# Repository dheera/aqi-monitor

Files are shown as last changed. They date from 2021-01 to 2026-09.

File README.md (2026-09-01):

# aqi-monitor

This DIY air quality monitor will measure:

- temperature
- humidity
- pressure
- gas
- CO2
- number of particles
- ozone (expansion)
- earthquakes through an IMU (expansion)
- radioactivity (expansion)

There's an optional case and screen for both. The code is set up to allow you to only use a subset of sensors.

By default, results are streamed periodically to a self-hosted server (see [server/](server/)) running InfluxDB and Grafana on your LAN, for easy inspection and alerting.

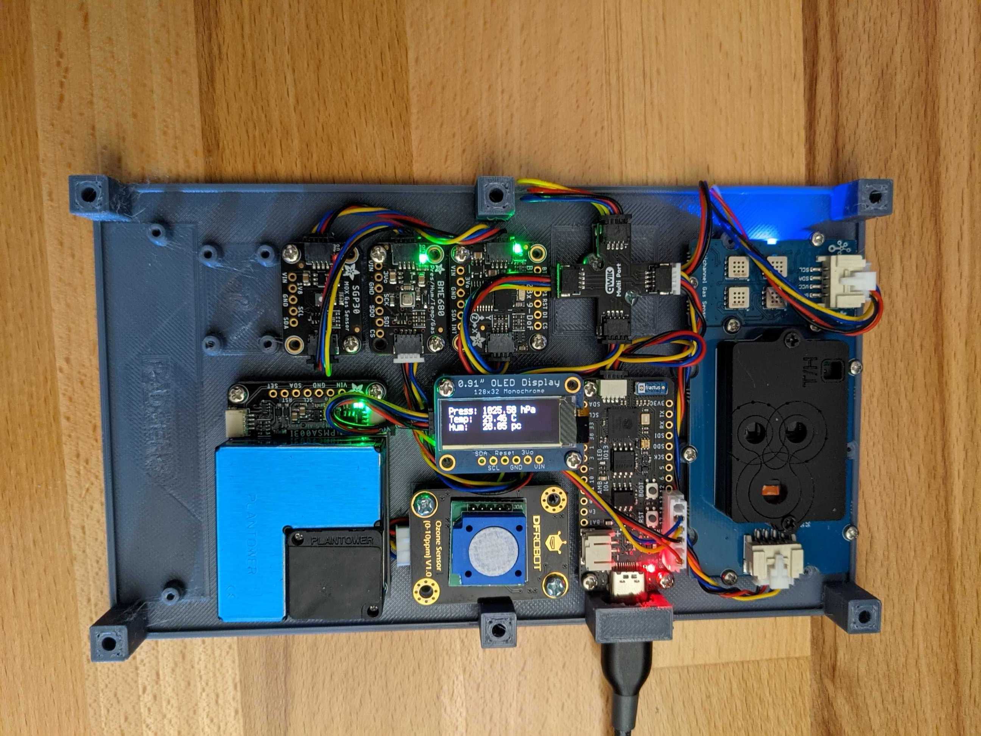
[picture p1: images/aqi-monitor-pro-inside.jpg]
sensor
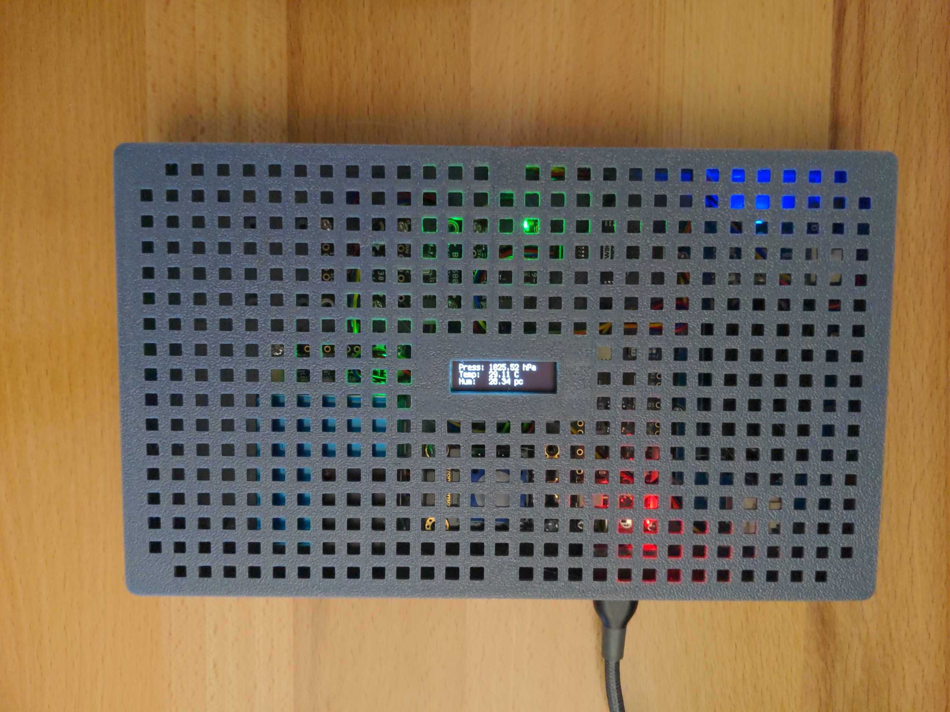
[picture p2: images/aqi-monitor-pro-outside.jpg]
cover
|  |  |
| --- | --- |

## BOM

If you want to encase the electronics, an STL file for 3D printing a case is in the [design folder](design/).
Make sure you get the right case for either base or base+expansion set.

### Base set

| item | function | ~price | notes |
| --- | --- | --- | --- |
| [Adafruit FeatherS2 - ESP32-S2](https://www.adafruit.com/product/4769) | microcontroller | $22 | adafruit boards are often available on digikey and amazon if adafruit is sold out |
| [Adafruit BME680](https://www.adafruit.com/product/3660) | Temp/Humidity/Pressure/Gas | $19 | incredibly sensitive pressure sensor, can possibly detect which floor of a building robot is on |
| [Adafruit PMSA003I](https://www.adafruit.com/product/4632) | PM1, PM2.5, PM10 particle sensor | $45 | this messes up the I2C bus it is placed on, thankfully ESP32-S2 has 2 I2C buses so this can have its own bus |
| [SeeedStudio SCD30](https://www.seeedstudio.com/Grove-CO2-Temperature-Humidity-Sensor-SCD30-p-2911.html) | CO2/temp/humidity sensor | $60 | NDIR CO2 sensor (much better than chemical); buy from Mouser for faster shipping to US destinations |

For a total of ~$146 excluding screen and case.

The STL files for 3D printing the base case can be found in the design folder.

### Expansion set

These are extra sensors you can purchase in addition to the base set.

| item | function | ~price | notes |
| --- | --- | --- | --- |
| [Adafruit BNO085](https://github.com/adafruit/Adafruit_BNO08x) | IMU (Earthquake detection) | $20 | this is a really good IMU |
| [SeeedStudio Multichannel Gas Sensor v2](https://www.seeedstudio.com/Grove-Multichannel-Gas-Sensor-v2-p-4569.html) | CO, VOC, alcohol, NO2 | $35 | buy from Mouser for faster shipping to US destinations |
| [DFRobot I2C Ozone Sensor](https://www.dfrobot.com/product-2005.html) | ozone | $49 | buy from Mouser for faster shipping to US destinations |
| [Geiger Counter](https://www.ebay.com/itm/Arduino-dosimeter-module-Geiger-Counter-RadSens-Radiation-Detector-board-pcb/184495660379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) | Radioactivity | $45 | ships from Russia; not yet tested; couldn't find a US-stocked I2C Geiger counter |

### Optional Screen

| item | function | ~price | notes |
| --- | --- | --- | --- |
| [Monochrome 0.91" 128x32 I2C OLED Display](https://www.adafruit.com/product/4440) | screen | $12.5  | optional |

## Instructions

### Wire the electronics

See pictures

### Set up the server

1. Follow [server/README.md](server/README.md) to bring up the InfluxDB + Grafana stack in Docker on a machine on your LAN, and generate an API key.

### Modify the parameters

1. Download the [code](code/) and open `wifi.json`. Enter your Wifi name (SSID) and password. The microcontroller needs WiFi access to be able to upload the sensor data.
2. Open `credentials.json` and set `url` to your server's address (e.g. `http://192.168.1.50:8080`), `device_id` to a name for this monitor, and `api_key` to the key you generated for the server.
3. Open [config.py](code/config.py) and modify any of the parameters (`LOAD_XXX`) to match your configuration.

### Load on the code

Plug the microcontroller into your computer using a USB-C cable. It should appear in your file explorer. Copy and replace the files from the `code` folder including the files you modified into the `CIRCUITPY` folder.

Press reset. You should see data coming through on the Grafana dashboard.

### Calibrate the sensors

The BME680 and SCD30 tend to read several degrees high for temperature due to
self-heating from nearby components. Correct for this once per physical unit:

1. Let the device run outside (or wherever you have a reliable reference
   temperature) for a few minutes so the sensors reach steady state.
2. Read `bme680.temperature` and `scd30.temperature` over the serial REPL (see
   Troubleshooting below) and compare against your reference thermometer.
3. In `config.py`, set `BME680_TEMP_OFFSET` and `SCD30_TEMP_OFFSET` to
   `sensor_reading - reference_temperature` for each sensor, then reload. Both
   default to `0.0` (no correction) until calibrated.

The SCD30's CO2 reading can drift over time and benefits from a one-time
forced recalibration (FRC) against a known-good reference, typically fresh
outdoor air (check the current atmospheric CO2 level rather than assuming the
outdated "400 ppm" figure). The sensor must have been running continuously
for at least 2 minutes before this. Over the serial REPL:

```
import board, busio, adafruit_scd30
i2c = busio.I2C(board.SCL, board.SDA, frequency=400000)
scd = adafruit_scd30.SCD30(i2c)
scd.forced_recalibration_reference = 425  # replace with your reference ppm
```

Unlike the temperature offsets, this value is stored on the SCD30's own
non-volatile memory rather than in this repo - it isn't reapplied
automatically and won't carry over if you swap sensors. There's no way to
read back when a sensor was last calibrated, so note the date and reference
value you used somewhere (e.g. a commit message) when you do it.

An alternative to a one-time FRC is enabling Automatic Self-Calibration
(`scd.self_calibration_enabled = True`), which continuously self-corrects
over about a week assuming the sensor sees fresh air periodically. Its
enabled state is not stored in non-volatile memory, so it turns off after
every reboot unless re-enabled in `code.py`.

## Troubleshooting

From a terminal window, you can log into the Feather S2 microcontroller to read the logs using

```
sudo screen /dev/ttyACM0 115200
```

The actual device name might be different. This opens up a python terminal. You can re-run the code by typing `import code`.

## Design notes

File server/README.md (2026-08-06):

# aqi-monitor server

Self-hosted replacement for the (now defunct) Freedom Robotics upload target. Runs three
containers on your LAN:

- **influxdb** — time-series database that stores the sensor readings
- **receiver** — small HTTP API the microcontroller posts JSON to; writes into InfluxDB
- **grafana** — dashboards and alerting on top of InfluxDB, pre-provisioned with a
  datasource and a starter dashboard (`grafana/provisioning/dashboards/aqi-monitor.json`)

## Setup

1. Copy the env template and fill in real secrets:

   ```
   cp .env.example .env
   ```

   Generate `INFLUXDB_TOKEN` and `API_KEY` as long random strings (e.g. `openssl rand -hex 32`).

2. Add a config file for each device under `devices/<device_id>.json` (an example is
   already there for `aqi-monitor-01`). This is where SGP30 IAQ baselines and any
   per-topic calibration coefficients live; the microcontroller fetches this at boot via
   `GET /devices/<device_id>/config`.

3. Start the stack:

   ```
   docker compose up -d --build
   ```

4. Grafana is at `http://<host>:3000` (login `admin` / `GRAFANA_PASSWORD` from `.env`).
   InfluxDB's own UI is at `http://<host>:8086` if you want to query data directly.

5. On the microcontroller, point `code/credentials.json` at this server:

   ```json
   {
     "url": "http://<host>:8080",
     "device_id": "aqi-monitor-01",
     "api_key": "<same value as API_KEY in .env>"
   }
   ```

## Data model

The receiver flattens each incoming message's nested `data` dict into InfluxDB fields
(e.g. `{"pm25_standard": 12}` under topic `pmsa003i/pm25_standard` becomes measurement
`pmsa003i_pm25_standard`, field `data`). Every point is tagged with `device=<device_id>`,
so a single stack can ingest multiple monitors.

## Long-term archival (optional)

InfluxDB retention can be capped and older data exported/archived to S3 on a schedule
(e.g. `influx backup` + a cron job pushing to a bucket) if you want cheap cold storage
beyond what you keep live in Grafana. This isn't set up by default.

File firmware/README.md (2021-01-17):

Modified CircuitPython firmware for FeatherS2 that resolves this bug
https://github.com/adafruit/circuitpython/issues/3988

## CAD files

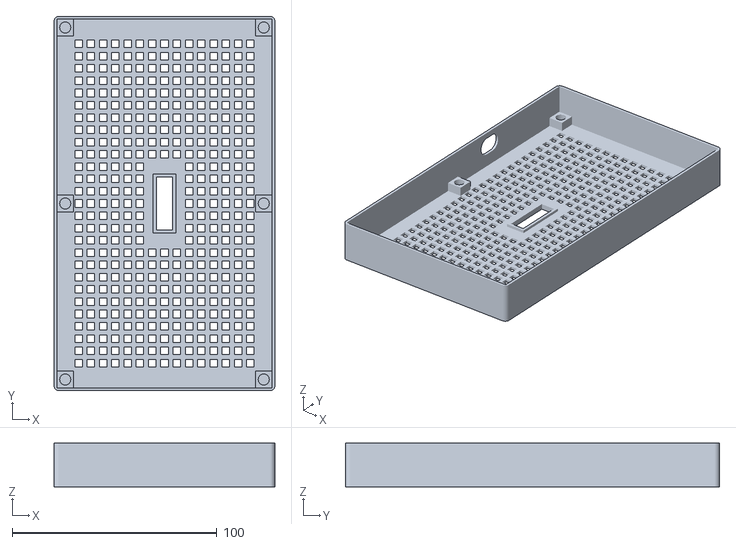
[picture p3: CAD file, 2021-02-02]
design/aqi-monitor-pro-cover.stl
108.0 x 183.0 x 21.5

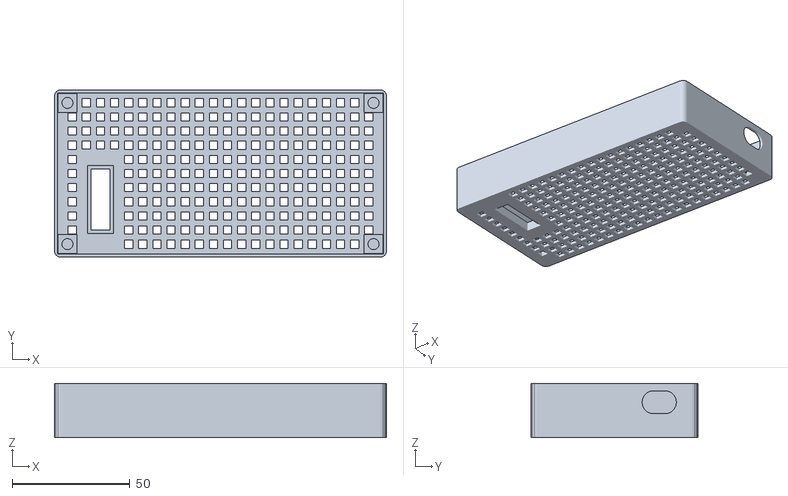
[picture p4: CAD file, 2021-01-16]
design/aqi-monitor-basic-cover.stl
141.0 x 71.0 x 23.0

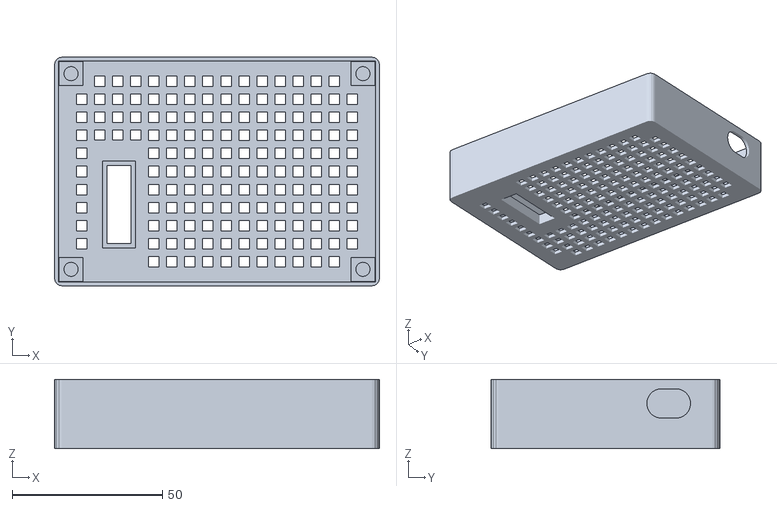
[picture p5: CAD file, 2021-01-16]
design/aqi-monitor-nano-cover.stl
108.0 x 76.0 x 23.0

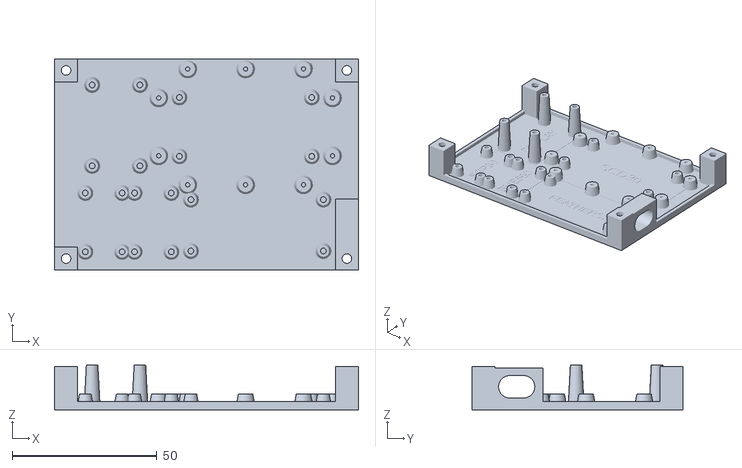
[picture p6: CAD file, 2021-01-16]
design/aqi-monitor-nano.stl
105.0 x 73.0 x 15.5

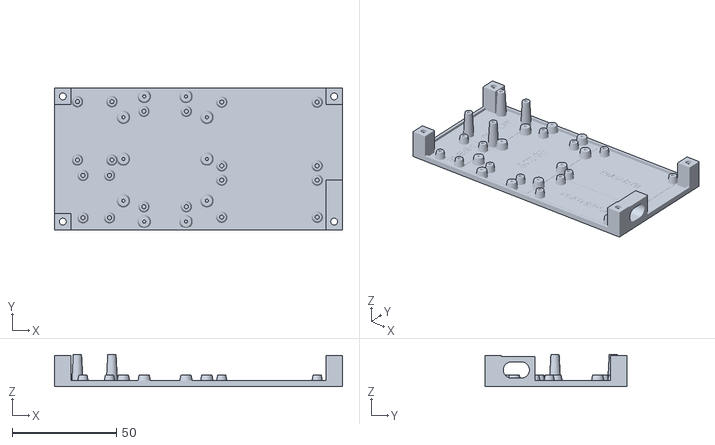
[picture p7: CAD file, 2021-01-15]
design/aqi-monitor-basic-base.stl
138.0 x 68.0 x 15.5

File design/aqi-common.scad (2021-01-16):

module usbplugshape(Q=12,R=7) {
    translate([-Q/2+R/2,0,0])
    cylinder(d=R,h=20,$fn=64);
    translate([Q/2-R/2,0,0])
    cylinder(d=R,h=20,$fn=64);
    cube_center([Q-R,R,20]);
}
    

module cube_center(dims,r=0,$fn=16) {
    if(r==0) {
        translate([-dims[0]/2, -dims[1]/2, 0])
        cube(dims);
    } else {
        minkowski() {
            translate([-(dims[0]-2*r)/2, -(dims[1]-2*r)/2, 0])
            cube([dims[0]-2*r,dims[1]-2*r,dims[2]]);
            cylinder(r=r,$fn=$fn,h=0.0001);
        }
    }
}




module usbport() {
    difference() {
    cube_center([8,18,13]);
    translate([-6,0,1+1.5+4])
    rotate([0,0,90])
    rotate([90,0,0])
        usbplugshape(Q=12.5,R=7.75);
    }
}

module usbplugshape(Q=12,R=7) {
    translate([-Q/2+R/2,0,0])
    cylinder(d=R,h=20,$fn=64);
    translate([Q/2-R/2,0,0])
    cylinder(d=R,h=20,$fn=64);
    cube_center([Q-R,R,20]);
}

module scd30() {
        difference() {
            union() {
    for(q=[-20:20:20]) for(r=[-20,20])
    translate([q,r,0]) standoff(sh=4,d=6,screw=2);
    for(q=[-30,30]) for(r=[-10,10])
    translate([q,r,0]) standoff(sh=4,d=6,screw=2);
    
    quadboard(W=2.0*25.4,H=1.0*25.4,w=1.8*25.4,h=.8*25.4,screw=2.5);
        cube_center([60,40,0.15]);
}
        linear_extrude(height = 0.5) text("SCD30", valign="center", halign="center",size=5);
    }
}


module tc6713() {
    difference() {
        cube_center([15+3,31+3,9.5]);
        translate([0,0,2.5])
        cube_center([15.3,31.3,8]);
        cube_center([13.3,31.3,8]);
        translate([0,11.15,0])
        cube_center([50,9,10]);
        translate([0,-11.15,0])
        cube_center([50,9,10]);
        cube_center([8,100,10]);
        translate([0,28,5])
        cube_center([30,30,10]);
        translate([0,-28,5])
        cube_center([30,30,10]);
    }
    translate([-20/2,0,0])
    standoff(sh=9.5);
    translate([20/2,0,0])
    standoff(sh=9.5);
}

module gamma() {
    
    
    difference() {
        cube_center([88,21,0.15]);
        linear_extrude(height = 0.5) text("RADSENS", valign="center", halign="center",size=4);
    }
    
    translate([83/2,21/2-8,0])
    standoff(sh=4,screw=2.5);
    translate([-83/2,21/2-8,0])
    standoff(sh=4,screw=2.5);
}

module mcgasv2() {
    translate([20/2,-40/2+10,0]) standoff(sh=4,d=6,screw=2);
    translate([-20/2,-40/2+10,0]) standoff(sh=4,d=6,screw=2);
    translate([20/2,40/2-10,0]) standoff(sh=4,d=6,screw=2);
    translate([-20/2,40/2-10,0]) standoff(sh=4,d=6,screw=2);
    translate([0,40/2,0]) standoff(sh=4,d=6,screw=2);
    translate([0,-40/2,0]) standoff(sh=4,d=6,screw=2);
    difference() {
        cube_center([20,40,0.15]);
        rotate([0,0,90])
        linear_extrude(height = 0.5) text("MCGASV2", valign="center", halign="center",size=4);
    }
}



module display() {
    quadboard(W=1.35*25.4,w=1.10*25.4,H=0.86*25.4,h=0.65*25.4, text = "DISPLAY",screw=2.5,sh=14);
}

module feathers2() {
    quadboard(W=50.5,w=45.75,H=22.5,h=17.75, text = "FEATHERS2",screw=2.5);
}

module pmsa003i() {
    quadboard(W=2.00*25.4,w=1.8*25.4,H=1.4*25.4,h=1.2*25.4, text="PMSA003I", screw=2.5);
}

module sen0321() {
    quadboard(W=37,w=30,H=27,h=20,sh=6.5,screw=3,d=6, text="SEN0321");
}

module bme680() {
    quadboard(W=1.0*25.4,w=0.8*25.4,H=0.70*25.4,h=0.5*25.4, text="BME680", screw=2.5);
}

module tsl2591() {
    quadboard(W=1.0*25.4,w=0.8*25.4,H=0.70*25.4,h=0.5*25.4, screw=2.5, text="?");
}

module sgp30() {
    quadboard(W=1.0*25.4,w=0.8*25.4,H=0.70*25.4,h=0.5*25.4, text="SGP30", screw=2.5);
}

module bno085() {
    quadboard(W=1.0*25.4,w=0.8*25.4,H=0.90*25.4,h=0.7*25.4, text="BNO085", screw=2.5);
}

module qwiicstar() {
    translate([-7.5/2,-7.5/2,0]) standoff(sh=4,d=6,screw=3);
    translate([7.5/2,7.5/2,0]) standoff(sh=4,d=6,screw=3);
    cube_center([26,26,0.15]);
}

module quadboard(W=25,w=20.25,H=18,h=13,sh=4,screw=2.5,d=5, text = "") {
    translate([-w/2,-h/2,0]) standoff(sh=sh,screw=screw,d=d);
    translate([-w/2,h/2,0]) standoff(sh=sh,screw=screw,d=d);
    translate([w/2,-h/2,0]) standoff(sh=sh,screw=screw,d=d);
    translate([w/2,h/2,0]) standoff(sh=sh,screw=screw,d=d);
    difference() {
        cube_center([W,H,0.15]);
        linear_extrude(height = 0.5) text(text, valign="center", halign="center",size=4);
    }
}

module standoff(d=5,screw=1.5,sh=4) {
    difference() {
        cylinder(d1=d+0.5,d2=d-1,h=sh,$fn=32);
        cylinder(d=screw-0.5,h=sh+1,$fn=32);
    }
}

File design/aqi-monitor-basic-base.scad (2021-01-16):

include<aqi-common.scad>;

/*
// fit testing
translate([0,0,23])
rotate([0,180,180])
import("aqi-monitor-basic-cover.stl");
*/

// width and height of board
W=138;
H=68;

// how much the whole board layout is offset from origin
TX=34;
TY=-23;

// how much the display is offset from center
DX=-51;
DY=11;

difference() {
    union() {
            cube_center([W,H,1.5]);
        difference() {
            cube_center([W,H,3]);
            cube_center([W-3,H-3, 6]);
            
        }
        for(s=[-1,1]) for(t=[-1,1])
            translate([s*(W-8)/2,t*(H-8)/2])
            cube_center([8,8,15]);
    }
    for(s=[-1,1]) for(t=[-1,1]) {
        translate([s*(W-8)/2,t*(H-8)/2]) {
            cylinder(d=6,h=3.5,$fn=32);
            cylinder(d=3.3,h=50,$fn=32);
        }
    }
}

translate([TX,TY,1.5]) {
    translate([31,4,0]) usbport();
    
    translate([0,4,0])
    feathers2();
    
    translate([-83,5,0])
    rotate([0,0,90])
    bme680();
    
    translate([0,35,0])
    pmsa003i();
    
    translate([-50,23,0])
    rotate([0,0,90])
    scd30();
    
    translate([DX,DY,0])
    translate([-TX,-TY,0])
    translate([(9-6.5)/2,(7.5-2.5)/2,0])
    rotate([0,0,90])
    display();
}

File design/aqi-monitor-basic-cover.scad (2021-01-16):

include<aqi-common.scad>;

W=138;
H=68;
TX=34;
TY=-23;
DX=-51;
DY=11;

{
  difference() {
      union() {
    cube_center([W+3,H+3,23],r=2.5);
          
      }
  translate([0,0,1.5])
  difference() {
      cube_center([W+.3,H+.3,23]);
      
      translate([DX,-DY,0])
      cube_center([11,29,0.5+2.5]);
  }
  difference() {
      for(x=[-63:6:63]) for(y=[-30:6:30])
      translate([x,y,0])
      cube_center([3.5,3.5,3]);
      
      translate([DX,-DY,0])
      cube_center([17,43,100]);
  }
  
  //translate([-60,27+4,23-8])
  translate([31+TX,-(   4+TY),23-8]) 
  //cube_center([100,16,11]);
  rotate([90,0,90]) {
        usbplugshape(Q=12.5+2,R=7.75+2);
    }
  
  translate([DX,-DY,0])
  cube_center([8,26,100]);
         
}

difference() {
              for(s=[-1,1]) for(t=[-1,1])
            translate([s*(W-8)/2,t*(H-8)/2])
            cube_center([8,8,8-0.15]);
          
  for(s=[-1,1]) for(t=[-1,1]) {
        translate([s*(W-8)/2,t*(H-8)/2,3]) {
            cylinder(d=4.7,h=5,$fn=32);
        }
    }
}

}

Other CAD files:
design/aqi-monitor-nano-cover.scad
design/aqi-monitor-nano.scad
design/aqi-monitor-pro-base.scad
design/aqi-monitor-pro-cover.scad

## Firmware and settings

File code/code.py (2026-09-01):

print("Starting ...")

import board
import busio
import display
import gc
import os
import sys
import time
import microcontroller
from config import *

time.sleep(5)

if LOAD_WATCHDOG:
    from watchdog import WatchDogMode
    w = microcontroller.watchdog
    w.timeout = 60.0
    w.mode = WatchDogMode.RESET
    w.feed()
    microcontroller.on_next_reset(microcontroller.RunMode.NORMAL)

print("import libraries")

if LOAD_UPLOAD:
    import nanolink
if LOAD_BME680:
    import adafruit_bme680
if LOAD_SGP30:
    import adafruit_sgp30
if LOAD_SCD30:
    import adafruit_scd30
if LOAD_MCGASV2:
    import seeed_mcgasv2
if LOAD_SEN0321:
    import dfrobot_ozone
if LOAD_BNO08X:
    import adafruit_bno08x
    from adafruit_bno08x.i2c import BNO08X_I2C
if LOAD_PMSA003I:
    from adafruit_pm25.i2c import PM25_I2C
if LOAD_RADSENSE:
    import radsense
if LOAD_WATCHDOG:
    w.feed()

print("init i2c")
gc.collect() # Clear memory before heavy sensor init
# Set to 400kHz for stability.
i2c = busio.I2C(board.SCL, board.SDA, frequency=400000)

if LOAD_PMSA003I:
    # PMSA003I needs its own i2c bus because it seems to mess with other i2c devices
    # it also needs a much lower i2c clock frequency per adafruit docs
    # fortunately the feathers2 has 2 i2c controllers and we can instantiate the 2nd one
    # on pins IO17 and IO18 which are very close to 3V and GND pins so
    # you can solder a JST-EH connector with 5 or more positions to [3V, 0, GND, 17, 18]
    # also, @unexpectedmaker warned on discord not to use IO0 for i2c
    i2c1 = busio.I2C(board.IO17, board.IO18, frequency=100000)

if LOAD_WATCHDOG:
    w.feed()

# Some sensor drivers (e.g. adafruit_bme680) block forever polling status
# registers instead of raising when the chip isn't actually on the bus, which
# would otherwise hang the watchdog-reset loop indefinitely. Scanning first
# and skipping absent addresses avoids ever calling into those drivers blind.
print("scanning i2c bus")
while not i2c.try_lock():
    pass
i2c_addrs = i2c.scan()
i2c.unlock()
print("i2c devices found:", [hex(a) for a in i2c_addrs])

if LOAD_PMSA003I:
    while not i2c1.try_lock():
        pass
    i2c1_addrs = i2c1.scan()
    i2c1.unlock()
    print("i2c1 devices found:", [hex(a) for a in i2c1_addrs])

if LOAD_BME680 and 0x77 not in i2c_addrs:
    print("bme680 not found on i2c bus scan")
    LOAD_BME680 = False
if LOAD_SGP30 and 0x58 not in i2c_addrs:
    print("sgp30 not found on i2c bus scan")
    LOAD_SGP30 = False
if LOAD_SCD30 and 0x61 not in i2c_addrs:
    print("scd30 not found on i2c bus scan")
    LOAD_SCD30 = False
if LOAD_MCGASV2 and 0x08 not in i2c_addrs:
    print("mcgasv2 not found on i2c bus scan")
    LOAD_MCGASV2 = False
if LOAD_SEN0321 and 0x73 not in i2c_addrs:
    print("sen0321 not found on i2c bus scan")
    LOAD_SEN0321 = False
if LOAD_BNO08X and 0x4A not in i2c_addrs:
    print("bno08x not found on i2c bus scan")
    LOAD_BNO08X = False
if LOAD_RADSENSE and 0x66 not in i2c_addrs:
    print("radsense not found on i2c bus scan")
    LOAD_RADSENSE = False

if LOAD_WATCHDOG:
    w.feed()

#If the display is physically disconnected or 
#has a loose wire, display.init(i2c) might crash 
#the entire script before it even starts monitoring
if LOAD_DISPLAY:
    print("init display")
    try:
        display.init(i2c)
    except Exception as e:
        print("Display not found or failed to init:", e)
        LOAD_DISPLAY = False # Disable display logic for the rest of the run


    if LOAD_WATCHDOG:
        w.feed()

print("init net")
display.show(0, "init net")

from net import requests, geo

if LOAD_WATCHDOG:
    w.feed()

if LOAD_UPLOAD:
    print("init link")
    display.show(0, "init link")
    link = nanolink.NanoLink(requests = requests, auto_sync = False)

    print("device config:")
    print(link.config)

    if LOAD_WATCHDOG:
        w.feed()

def log(text):
    print(text)
    link.log("info", text)
    link.sync()


if LOAD_BNO08X:
    print("init bno08x")
    display.show(0, "init bno08x")
    link.log("info", "init bno08x")
    link.sync()

    try:
        bno = BNO08X_I2C(i2c)
        bno.enable_feature(adafruit_bno08x.BNO_REPORT_ACCELEROMETER)
        bno.enable_feature(adafruit_bno08x.BNO_REPORT_GYROSCOPE)
        bno.enable_feature(adafruit_bno08x.BNO_REPORT_MAGNETOMETER)
        bno.enable_feature(adafruit_bno08x.BNO_REPORT_ROTATION_VECTOR)
    except Exception as e:
        print("bno08x not found or failed to init:", e)
        LOAD_BNO08X = False

    if LOAD_WATCHDOG:
        w.feed()

if LOAD_MCGASV2:
    print("init mcgasv2")
    display.show(0, "init mcgasv2")
    link.log("info", "init mcgasv2")
    link.sync()

    try:
        gas = seeed_mcgasv2.Gas(i2c)
    except Exception as e:
        print("mcgasv2 not found or failed to init:", e)
        LOAD_MCGASV2 = False

    if LOAD_WATCHDOG:
        w.feed()

if LOAD_BME680:
    print("init bme680")
    display.show(0, "init bme680")
    link.log("info", "init mcgasv2")
    link.sync()

    bme680 = None
    try:
        bme680 = adafruit_bme680.Adafruit_BME680_I2C(i2c)
    except Exception as e:
        print("bme680 not found or failed to init:", e)
        LOAD_BME680 = False

    if LOAD_WATCHDOG:
        w.feed()

if LOAD_SGP30:
    print("init sgp30")
    display.show(0, "init sgp30")
    link.log("info", "init sgp30")
    link.sync()

    try:
        sgp30 = adafruit_sgp30.Adafruit_SGP30(i2c)
        print("SGP30 serial # %04x-%04x-%04x" % tuple(sgp30.serial))
        sgp30.iaq_init()
        iaq_baseline = link.config.get("sgp30", {}).get("iaq_baseline", [0x8973, 0x8AAE])
        if len(iaq_baseline) != 2 or type(iaq_baseline[0]) != int or type(iaq_baseline[1]) != int:
            iaq_baseline = [0x8973, 0x8AAE]
        sgp30.set_iaq_baseline(iaq_baseline[0], iaq_baseline[1])
    except Exception as e:
        print("sgp30 not found or failed to init:", e)
        LOAD_SGP30 = False

    if LOAD_WATCHDOG:
        w.feed()

if LOAD_SCD30:
    print("init scd30")
    display.show(0, "init scd30")
    link.log("info", "init scd30")
    link.sync()

    try:
        scd30 = adafruit_scd30.SCD30(i2c)
        scd30.temperature_offset = SCD30_TEMP_OFFSET
    except Exception as e:
        print("scd30 not found or failed to init:", e)
        LOAD_SCD30 = False

    if LOAD_WATCHDOG:
        w.feed()

if LOAD_SEN0321:
    print("init sen0321")
    display.show(0, "init sen0321")
    link.log("info", "init sen0321")
    link.sync()

    try:
        ozone = dfrobot_ozone.DFRobot_Ozone(i2c)
        if ozone is not None:
            ozone.set_mode(dfrobot_ozone.MEASURE_MODE_AUTOMATIC)
    except Exception as e:
        print("sen0321 not found or failed to init:", e)
        LOAD_SEN0321 = False

    if LOAD_WATCHDOG:
        w.feed()

if LOAD_PMSA003I:
    print("init pm25")
    display.show(0, "init pm25")
    link.log("info", "init pm25")
    link.sync()

    pm25 = None
    try:
        pm25 = PM25_I2C(i2c1, None)
    except Exception as e:
        print("pmsa003i not found or failed to init:", e)
        LOAD_PMSA003I = False

    if LOAD_WATCHDOG:
        w.feed()

if LOAD_RADSENSE:
    print("init radsense")
    display.show(0, "init radsense")
    link.log("info", "init radsense")
    link.sync()

    try:
        radsense = radsense.Radsense_1_2(i2c)
    except Exception as e:
        print("radsense not found or failed to init:", e)
        LOAD_RADSENSE = False

display_page = 0

seq = 0

while True:

    display_page = (display_page + 1) % 6

    t = time.monotonic_ns()

    data = []

    if LOAD_PMSA003I:
        try:
            aqdata_filtered = {}
            aqdata = pm25.read()
            for key in aqdata:
               aqdata_filtered[key.replace(" ", "_")] = aqdata[key]
            data.append(("/pmsa003i/raw", "pmsa003i_msgs/RawData", aqdata_filtered))
            data.append(("/pmsa003i/pm10_standard", "std_msgs/Float32", {"data": aqdata_filtered["pm10_standard"]}))
            data.append(("/pmsa003i/pm25_standard", "std_msgs/Float32", {"data": aqdata_filtered["pm25_standard"]}))
            data.append(("/pmsa003i/pm100_standard", "std_msgs/Float32", {"data": aqdata_filtered["pm100_standard"]}))
            if display_page == 0:
                display.show(0, "PM2.5:  %.1f" % aqdata_filtered["pm25_standard"])
                display.show(1, "PM10:   %.1f" % aqdata_filtered["pm10_standard"])
                display.show(2, "PM100:  %.1f" % aqdata_filtered["pm100_standard"])
        except RuntimeError as e:
            print("error reading pm25 data")
            sys.print_exception(e)

    if LOAD_SGP30:
        try:
            data.append(("/sgp30/tvoc", "std_msgs/Float32", {"data": sgp30.TVOC}))
            data.append(("/sgp30/eco2", "std_msgs/Float32", {"data": sgp30.eCO2}))
            data.append(("/sgp30/baseline_tvoc", "std_msgs/Float32", {"data": sgp30.baseline_TVOC}))
            data.append(("/sgp30/baseline_eco2", "std_msgs/Float32", {"data": sgp30.baseline_eCO2}))
            if display_page == 1:
                display.show(0, "eCO2:   %.2f ppm" % sgp30.eCO2)
                display.show(1, "TVOC:   %.2f ppb" % sgp30.TVOC)
                display.show(2, " ")
        except Exception as e:
            print("error reading sgp30 data")
            sys.print_exception(e)

    if LOAD_SCD30:
        try:
            if scd30.data_available:
                co2 = scd30.eCO2
                humidity = scd30.relative_humidity
                temp = scd30.temperature
                if co2 > 0:
                    data.append(("/scd30/co2", "std_msgs/Float32", {"data": co2}))
                if humidity > 0:
                    data.append(("/scd30/humidity", "std_msgs/Float32", {"data": humidity}))
                if temp > 0:
                    data.append(("/scd30/temp", "std_msgs/Float32", {"data": temp}))
                if display_page == 2:
                    display.show(0, "CO2:   %.2f ppm" % co2)
                    display.show(1, "Hum:   %.2f pc" %humidity)
                    display.show(2, "Temp:  %.2f C" % temp)
        except Exception as e:
            print("error reading scd30 data")
            sys.print_exception(e)

    if LOAD_MCGASV2:
        try:
            gas_data = gas.measure_all()
            data.append(("/mcgasv2/raw", "mcgasv2_msgs/RawData", {"gm102b": gas_data[0], "gm302b": gas_data[1], "gm502b": gas_data[2], "gm702b": gas_data[3]}))
            if display_page == 3:
                display.show(0, "102: %1.2f 302: %1.2f" % (gas_data[0], gas_data[1]))
                display.show(1, "502: %1.2f 702: %1.2f" % (gas_data[2], gas_data[3]))
                display.show(2, " ")
        except Exception as e:
            print("error reading mcgasv2 data")
            sys.print_exception(e)

    if LOAD_SEN0321:
        try:
            ozone_ppb = ozone.get_ozone_data(10)
            data.append(("/sen0321/ozone", "std_msgs/Float32", {"data": ozone_ppb}))
            if display_page == 4:
                display.show(0, "O3: %.2f ppb" % ozone_ppb)
                display.show(1, " ")
                display.show(2, " ")
        except Exception as e:
            print("error reading ozone data")
            sys.print_exception(e)

    if LOAD_BME680:
        try:
            data.append(("/bme680/pressure", "std_msgs/Float32", {"data": bme680.pressure}))
            if LOAD_SCD30:
                scd30.ambient_pressure = int(bme680.pressure)
            data.append(("/bme680/humidity", "std_msgs/Float32", {"data": bme680.relative_humidity}))
            data.append(("/bme680/temp", "std_msgs/Float32", {"data": bme680.temperature - BME680_TEMP_OFFSET}))
            data.append(("/bme680/gas", "std_msgs/Float32", {"data": bme680.gas}))
            if display_page == 5:
                display.show(0, "Press: %.2f hPa" % bme680.pressure)
                display.show(1, "Temp:  %.2f C" % (bme680.temperature - BME680_TEMP_OFFSET))
                display.show(2, "Hum:   %.2f pc" % bme680.relative_humidity)
        except Exception as e:
            print("error reading bme680 data")
            sys.print_exception(e)

    if LOAD_RADSENSE:
        try:
            radsense.update_data()
            data.append(("/radsense/pulse_count", "std_msgs/Int32", {"data": radsense.get_pulse_count()}))
            data.append(("/radsense/rad_intensity_dynamic", "std_msgs/Float32", {"data": radsense.get_rad_intensity_dynamic()}))
            data.append(("/radsense/rad_intensity_static", "std_msgs/Float32", {"data": radsense.get_rad_intensity_static()}))
        except Exception as e:
            print("error reading radsense data")
            sys.print_exception(e)

    if LOAD_BNO08X:
        pass
        # TODO: do something with IMU data (detect earthquakes?)
        # print("acc", bno.acceleration)
        # print("gyr", bno.gyro)
        # print("mag", bno.magnetic)
        # print("quat", bno.quaternion)

    if LOAD_UPLOAD:
        calibration = link.config.get("calibration", {})
        for topic, _type, msg in data:
            if topic in calibration:
                coeffs = calibration[topic]
                if "data" in msg:
                    in_value = msg["data"]
                    out_value = 0
                    for power, c in enumerate(coeffs):
                        out_value += c * in_value ** power
                    msg["data"] = out_value

            link.message(topic, _type, msg)

    if "location" in geo:
        link.message("/fix", "sensor_msgs/NavSatFix", {
            "header": {
                "seq": 0,
                "stamp": {
                    "secs": time.time(),
                    "nsecs": 0,
                },
                "frame_id": "base_link",
            },
            "latitude": geo["location"].get("lat", 0),
            "longitude": geo["location"].get("lng", 0),
            "position_covariance": [
                geo["location"].get("accuracy", 100),
                0,
                0,
                0,
                geo["location"].get("accuracy", 100),
                0,
                0,
                0,
                geo["location"].get("accuracy", 100)**2,
            ],
            "position_covariance_type": 1,
        })

    print("loop", (time.monotonic_ns() - t)/1.0e6, "ms")

    try:
        if LOAD_UPLOAD and link.sync():
            # sync to server was successful
            if LOAD_WATCHDOG:
                w.feed()
    except Exception as e:
        sys.print_exception(e)

    seq += 1

    if seq % 10000 == 0:
        if LOAD_DISPLAY:
            print("init display")
            display.init(i2c)

    time.sleep(2)

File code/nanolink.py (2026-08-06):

import json
import rtc
import sys
import time

__version__ = "2.0.0"

LOG_LEVELS = {"debug": 1, "info": 2, "warn": 4, "warning": 4, "error": 8, "fatal": 16}
DEBUG = 1
INFO = 2
WARN = 4
ERROR = 8
FATAL = 16

class NanoLink(object):
    """Streams sensor data as JSON to a self-hosted ingestion server (see server/)."""

    def __init__(self, url = None, device_id = None, api_key = None, auto_sync = True, auto_time_sync = True, requests = None, debug = False, max_queue_size = 127):
        self.__version__ = __version__
        self.auto_sync = auto_sync
        self.debug = debug
        self.requests = requests
        self.max_queue_size = max_queue_size
        self.config = {}

        if self.requests is None:
            import requests
            self.requests = requests

        if url is None or device_id is None or api_key is None:
            with open("credentials.json") as f:
                credentials = json.loads(f.read())
            self.url = credentials["url"]
            self.device_id = credentials["device_id"]
            self.api_key = credentials["api_key"]
        else:
            self.url = url
            self.device_id = device_id
            self.api_key = api_key

        self._time_url = "%s/utc_now" % self.url.rstrip("/")
        self._data_url = "%s/devices/%s/data" % (self.url.rstrip("/"), self.device_id)
        self._config_url = "%s/devices/%s/config" % (self.url.rstrip("/"), self.device_id)
        self._outgoing_message_queue = []

        if auto_time_sync:
            self.sync_time()

        self.fetch_config()

    def sync_time(self):
        try:
            result = self.requests.get(self._time_url, timeout = 10)
            if result.status_code == 200:
                utc_time = time.localtime(int(json.loads(result.content)["timestamp"]))
                rtc.RTC().datetime = utc_time
                return True
            else:
                print("[nanolink] sync_time error: " + str(result.status_code))
        except Exception:
            print("[nanolink] sync_time error")

        return False

    def fetch_config(self):
        headers = {"x-api-key": self.api_key}
        try:
            result = self.requests.get(self._config_url, headers = headers, timeout = 10)
            if result.status_code == 200:
                self.config = json.loads(result.content)
            else:
                print("[nanolink] fetch_config error: " + str(result.status_code))
        except Exception:
            print("[nanolink] fetch_config error")

        return self.config

    def sync(self):
        if not self._outgoing_message_queue:
            return True

        headers = {
            "x-api-key": self.api_key,
            "content-type": "application/json",
        }

        if self.debug:
            print(self._data_url)
            print(self._outgoing_message_queue)

        try:
            result = self.requests.post(
                self._data_url,
                headers = headers,
                json = self._outgoing_message_queue,
                timeout = 5,
            )
            if result.status_code != 200:
                print("[nanolink] sync error: " + str(result.status_code) + ": " + result.content)
                return False
            else:
                self._outgoing_message_queue = []
        except Exception as e:
            sys.print_exception(e)
            return False

        return True

    def log(self, level, msg, stack_trace=None):
        if type(level) is str:
            level_int = LOG_LEVELS[level]
        else:
            level_int = level

        self.message(
            "/logs",
            "log_msgs/Log",
            {
                "level": level_int,
                "msg": msg,
            }
        )

    def message(self, topic, topic_type, msg):
        self._outgoing_message_queue.append({
            "utc_time": time.time(),
            "topic": topic,
            "type": topic_type,
            "data": msg,
        })

        while len(self._outgoing_message_queue) > self.max_queue_size:
            del(self._outgoing_message_queue[0])

        if self.auto_sync:
            self.sync()

if __name__ == "__main__":
    print("Running test")

    import random

    link = NanoLink()

    while True:
        time.sleep(0.5)
        value = random.random()
        print("Sending " + str(value))
        link.message("/random", "std_msgs/Float32", {"data": value})

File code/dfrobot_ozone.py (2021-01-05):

# -*- coding: utf-8 -*
""" 
  @file DFRobot_Ozone.py
  @note DFRobot_Ozone Class infrastructure, implementation of underlying methods
  @copyright   Copyright (c) 2010 DFRobot Co.Ltd (http://www.dfrobot.com)
  @licence     The MIT License (MIT)
  @author      [ZhixinLiu](zhixin.liu@dfrobot.com)
  version  V1.0
  date  2020-5-27
  @get from https://www.dfrobot.com
  @url https://github.com/DFRobot/DFRobot_Ozone
"""

ADDRESS_0                 = 0x70           # iic slave Address
ADDRESS_1                 = 0x71
ADDRESS_2                 = 0x72
ADDRESS_3                 = 0x73

MEASURE_MODE_AUTOMATIC    = 0x00           # active  mode
MEASURE_MODE_PASSIVE      = 0x01           # passive mode

AUTO_READ_DATA            = 0x00           # auto read ozone data
PASSIVE_READ_DATA         = 0x01           # passive read ozone data

MODE_REGISTER             = 0x03           # mode register
SET_PASSIVE_REGISTER      = 0x04           # read ozone data register

AUTO_DATA_HIGE_REGISTER   = 0x09           # auto data high eight bits
AUTO_DATA_LOW_REGISTER    = 0x0A           # auto data Low  eight bits

PASS_DATA_HIGE_REGISTER   = 0x07           # auto data high eight bits
PASS_DATA_LOW_REGISTER    = 0x08           # auto data Low  eight bits
  
class DFRobot_Ozone(object):
  __m_flag   = 0              # mode flag
  __count    = 0              # acquisition count    
  __txbuf      = [0]          # iic send buffer
  __ozonedata  = [0]*101      # ozone data
  def __init__(self, i2c, addr = ADDRESS_3):
    self.__addr = addr
    self.i2c = i2c

  ''' 
    @brief set the mode to read the data
    @param mode MEASURE_MODE_AUTOMATIC or MEASURE_MODE_PASSIVE
  '''
  def set_mode(self ,mode):
    if mode ==  MEASURE_MODE_AUTOMATIC:
      __m_flag = 0
      self.__txbuf[0] = MEASURE_MODE_AUTOMATIC 
      self.write_reg(MODE_REGISTER ,self.__txbuf)
    elif mode == MEASURE_MODE_PASSIVE:
      __m_flag = 1
      self.__txbuf[0] = MEASURE_MODE_PASSIVE
      self.write_reg(MODE_REGISTER ,self.__txbuf)
    else:
      __m_flag = 2
      return

  ''' 
    @brief get the ozone data ,units of PPB
    @param collectnum Collect the number
    @return  Ozone concentration, (units PPB)
  '''
  def get_ozone_data(self ,collectnum):
    if collectnum > 0:
      for num in range(collectnum ,1 ,-1):
        self.__ozonedata[num-1] = self.__ozonedata[num-2];
      if self.__m_flag == 0:
        self.__txbuf[0] = AUTO_READ_DATA
        self.write_reg(SET_PASSIVE_REGISTER ,self.__txbuf)
        self.__ozonedata[0] = self.get_ozone(AUTO_DATA_HIGE_REGISTER)
      elif self.__m_flag == 1:
        self.__txbuf[0] = PASSIVE_READ_DATA
        self.write_reg(SET_PASSIVE_REGISTER ,self.__txbuf)
        self.__ozonedata[0] = get_ozone(PASS_DATA_HIGE_REGISTER)
      if self.__count < collectnum:
        self.__count += 1
      return self.get_average_num(self.__ozonedata ,self.__count)
    elif (collectnum > 100) or (collectnum <= 0):
      return -1

  ''' 
    @brief get the average of the ozone data ,units of PPB
    @param barry ozone data group
    @param Len The number of data
    @return  Ozone concentration, (units PPB)
  '''
  def get_average_num(self ,barry ,Len):
    temp = 0
    for num in range (0 ,Len):
      temp += barry[num]
    return (temp / Len)

  ''' 
    @brief get the ozone data, units of PPB
    @param reg register address
    @return  Ozone concentration, (units PPB)
  '''
  def get_ozone(self,reg):
    rslt = self.read_reg(reg ,2)
    return ((rslt[0] << 8) + rslt[1])

  def write_reg(self, reg, data):
    while not self.i2c.try_lock():
        pass
    self.i2c.writeto(self.__addr, bytes([reg] + data))
    self.i2c.unlock()

  def read_reg(self, reg ,len):
    while not self.i2c.try_lock():
        pass
    self.i2c.writeto(self.__addr, bytes([reg]))
    result = bytearray(len)
    self.i2c.readfrom_into(self.__addr, result)
    self.i2c.unlock()
    return result

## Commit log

2021-01-15 3d print files
    [aqi-monitor-base.scad, aqi-monitor-cover.scad, aqi-monitor-cover.stl]
2021-01-15 basic base
    [aqi-monitor-basic-base.scad]
2021-01-15 accept adafruit or seeed scd30
    [aqi-monitor-basic-base.scad, aqi-monitor-pro-base.scad]
2021-01-16 add nano
    [aqi-monitor-nano.scad, aqi-monitor-nano.stl]
2021-01-16 add covers
    [aqi-common.scad, aqi-monitor-basic-base.scad, aqi-monitor-basic-cover.scad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]
2021-01-25 fix errors with bme680 when scd30 is not present
    [code.py]
2021-01-25 periodically time sync in case clock drifts
    [code.py, net.py]
2021-01-26 fix errors in time syncing from freedom server due to single precision floats
    [net.py]
2021-01-27 catch sync errors instead of rebooting
    [code.py]
2021-01-27 print sync error before raising
2021-02-01 design update
    [aqi-monitor-pro-base.scad, aqi-monitor-pro-cover.scad, aqi-monitor-pro-cover.stl]
2021-03-16 fixes out of sockets issue
2021-03-17 reset display every 10000s
    [code.py]
2026-08-06 Replace FreedomRobotics upload with self-hosted InfluxDB/Grafana server
    FreedomRobotics is being dropped in favor of a self-hosted stack (server/)
    so data stays on the local network. code.py/config.py switch from the
    freedomrobotics module to nanolink, gated by LOAD_UPLOAD instead of
    LOAD_FREEDOM, and read device config from credentials.json (url,
    device_id, api_key) instead of Freedom account/device/token/secret.
    Also scans the I2C bus on boot and skips sensors that aren't present,
    and wraps each sensor's init in try/except so one missing/failed sensor
    no longer blocks the rest of the loop.
    credentials.json and wifi.json are now gitignored instead of tracked
    with placeholder values, to st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
    [code.py, config.py, nanolink.py]
2026-08-10 Move BME680/SCD30 self-heating offsets into config.py
    Applies both as config-driven corrections instead of a hardcoded
    constant (BME680) and a one-off REPL command on the sensor's own NVM
    (SCD30), so a fresh device defaults to no correction (0.0) and a
    calibrated one documents its actual offset in one place.
    [code.py, config.py]
2026-08-10 Document sensor calibration in README
    Covers the BME680/SCD30 temperature offset workflow now in config.py
    and the SCD30 CO2 forced recalibration procedure, which wasn't
    documented anywhere despite being a real one-time setup step.
2026-08-10 fix: set default for all sensors to load back to true, fix readme reference
    [config.py]
